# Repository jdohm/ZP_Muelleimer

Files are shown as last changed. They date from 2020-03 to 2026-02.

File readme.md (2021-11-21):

# Mülleimer Projekt der Zukunftspiloten aus dem Bergischen Land
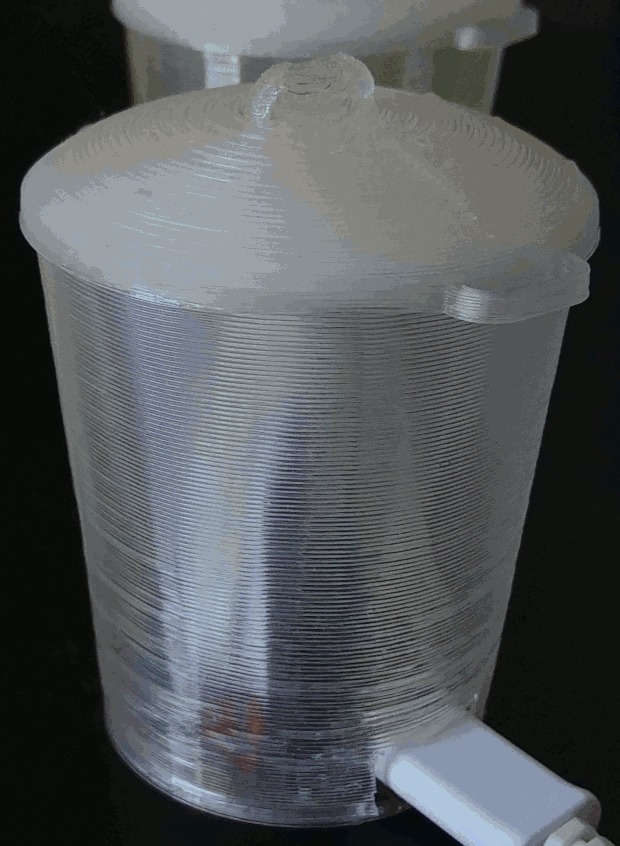
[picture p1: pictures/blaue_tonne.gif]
GIF blaue Mülltonne Abbildung vom Lötvorgang

## Zur Hardware:

| Anzahl | Bezeichnung |
|:---:|--- |
| 1 | Wemos D1 Mini ESP8266 Board  |
| 6 LED* | WS2812b LED-Streifen |
| 1 | USB-Kabel Ladekabel |
| 1 | USB-Netzteil |
| ~20g | (klares) Filament |

*wir nutzen ca 10 cm LED-Streifen (vom Typ WS2812b, mit 60 LED/Metern, also 6 LED pro Streifen. Dieser lässt sich mit 5 V unseres Boards betreiben. In der mitte geknickt passt er gut in unseren Mülleimer und zeigt so 3 LED zu jeder Seite.)

## Zum Hardware Aufbau

### Aufbau des Mülleimers
Der Mülleimer besteht aus einem 3D-Druck.
Hierzu gibt es zwei Varianten, die "simple" für Einsteiger und die "advanced" für Fortgeschrittene. 

1. Zur Erstellung des unteren 3D-Modells könnt ihr der Anleitung im Ordner 3D-Parts/bottom_simple oder 3D-Parts/bottom_advanced folgen. In beiden Ordnern befinden sich auch Beispielhaft fertige Datein. Das Ergebnis muss als *.stl exportiert werden, damit dieses später weiterverarbeitet werden kann. Speichert euch auch die Datei ab, falls ihr diese später noch einmal ändern wollt. *Hinweis* Das Modell darf innen gefüllt sein, da wir das später beim Drucken ändern.

2. Jetzt benötigen wir noch einen Deckel für unsere Tonne. Dazu findet sich ebenfalls unter 3D-Parts eine einfache Anleitung. Gerne könnt ihr natürlich auch euren eigenen Deckel kreieren. Achtet nur darauf das er auf unsere Tonne passt, und das wir den Deckel nicht im *Vasemode* Drucken. Deswegen sollten wir ihn nicht gefüllt konstruieren.

3. 3D-Drucken

    Bei dem Druck der Tonne und des Deckels brauchen wir unterschiedliche Einstellungen. Fangen wir mit der Tonne an. 
    Um eine möglichst durchscheinende Tonne zu bekommen nutzen wir nur eine Außenwand. Hier nutzen wir den *Vase mode* bei Cura heißt die Einstellung hierfür *spiralize outer contour*. Dazu nutzen wir bei einer Standard 0.4mm Düse eine *line width* von 0.48mm um unsere Tonne etwas stabiler zu gestalten. Es bietet sich an 3 *bottom layer* und eine *layer height* von 0.2-0.3mm einzustellen.

    Der einfache Deckel kann mit den Standardeinstellungen deines Druckers gedruckt werden. Eine *line width* von 0.48mm ist dabei Hilfreich aber nicht notwendig.

4. Anlöten der LED-Streifen

    Unter: [carontepass.files.wordpress.com](https://carontepass.files.wordpress.com/2016/03/wemos-d1-mini.jpg?w=1200) finden wir einen Bild mit dem Pinout des wemos D1 mini 

    Leider entpricht die Reihenfolge des LED-Streifens nicht der unseres Microkontrollers. Aus diesem Grund müssen wir mit ein paar kurzen Leitungen nachhelfen. Auch sollten wir nicht den Pin D4 nutzen, da dieser mit der internen blauen LED Verbunden ist.
    Wie hier in der Abbildung zu sehen wird die Seite des LED-Streifens auf der **Din** steht mit der Seite des Microkontrollers verbunden auf der sich die USB-Buchse befindet.

    Verbunden wird: 

    | LED | Microkontrollers |
    |:------:|-------------  |
    | +5V | 5V |
    | Din | D2 |
    | GND | G  |

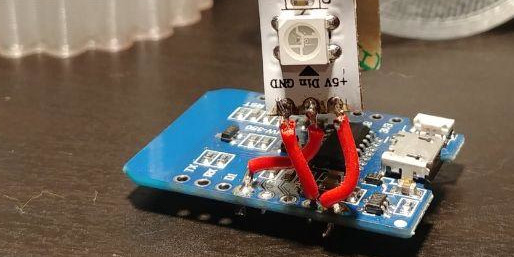
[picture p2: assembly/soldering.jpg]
Abbildung vom Lötvorgang
    

    *Hinweis* In der Arduino Umgebung heißt der Pin D2 "4". Das liegt daran das der Arduino den Wemos D1 mit den Nummern des eingebauten ESP8266 anspricht, die Hersteller vom Wemos D1 die aber umbenannt haben (zum Beispiel eben 4 in D2, oder Pin 2 in D4). Auf D4/Pin2 liegt die interne LED. Diese können wir im Arduino aber auch über *LED_BUILTIN* ansprechen.

5. Zusammenbau

    Mit einem Elektronikseitenschneider wird unten knapp über dem Boden ein Loch in unsere Tonne geschnitten sodass das kleine Ende vom USB-Kabel hindurch passt.
    Anschließend wird das Kabel hindurchgeführt, und an den Wemos D1 mini angeschlossen. Vorsichtig wird das Kabel wieder soweit hinaus gezogen, dass der Microkontroller am Boden liegt und der LED Streifen nach oben zeigt.

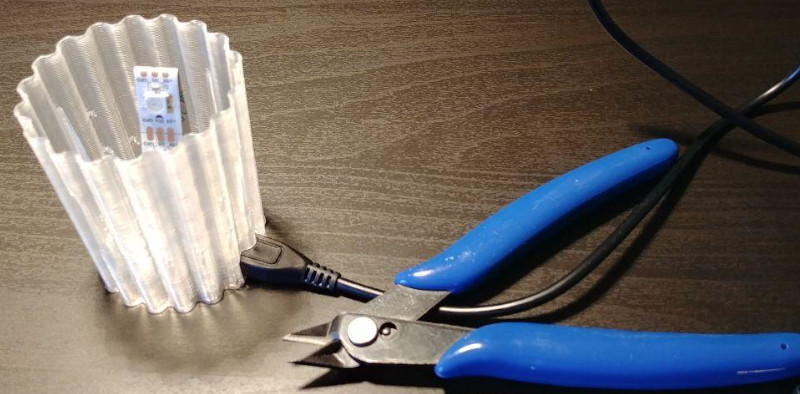
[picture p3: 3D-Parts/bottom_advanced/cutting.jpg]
Abbildung von Mülleimer und Seitenschneider
    

    Anschließend kann der Deckel einfach aufgesetzt werden.

## Zur Programmierung:

### Beschaffen und Installieren aller benötigten Bibliotheken
Ich gehe davon aus, das du bereits die Arduino IDE installiert hast, wenn nicht findest du sie hier: https://www.arduino.cc/en/software

1.   Installation des ESP8266 Moduls für Arduino https://github.com/esp8266/Arduino hier haben wir die "Installing with Boards Manager" Option gewählt. Nicht vergessend anschließend als Board den Wemos D1 R2&Mini auswählen

2.  Aus dem gleichen Set nutzen wir auch die ```ESP8266Wifi.h``` Library. Eine (englisches) Handbuch dazu findet sich hier:
[arduino-esp8266.readthedocs.io](https://arduino-esp8266.readthedocs.io/en/latest/esp8266wifi/readme.html)
hier gibt es auch ein [Beispiel Wifi Cleint](https://arduino-esp8266.readthedocs.io/en/latest/esp8266wifi/client-examples.html), bei dem ein Client aufgesetzt wird.

    Um die aktuelle Zeit und das Dazum zu kennen nutzen wir die Uhrzeit aus dem Internet. Dazu kann die folgende Anleitung genutzt werden: [simple-circuit.com](https://simple-circuit.com/esp8266-esp-01-internet-clock-wifi/). Hier wird erklärt wie wir eine Uhrzeit über NTP beziehen können. 
    Anschließend kann mit der Time Bibliothek die Linux-Uhrzeit in ein Datum umgerechnet werden. Die Informationen dazu finden wir hier: [github.com Time](https://github.com/PaulStoffregen/Time)

    * ICal (*.ics Datei) Version:

        Diese Version nutzt ICal Datein, einige Städte bieten diese zum Download für ihre Bürger an. Beispielsweise in Bochum oder Wuppertal.

        Um die Daten aus der Kalender Datei zu verwenden müssen wir den Kalender erst einmal auf unseren ESP bekommen. Dazu nutzen wir das ESP8266 Filesystem. Eine Anleitung dazu finden wir hier: [ESP Filesystem](http://arduino.esp8266.com/Arduino/versions/2.0.0/doc/filesystem.html) In dieser Anleitung wird auch erkärt, wie wir Daten von der Arduino Programmierumgebung (IDE) auf den ESP Laden.
        Hierbei muss darauf geachtet werden, die neuste Version zu nutzen, *nicht* die im Artikel verlinkte.

        Anschließend kann mit der [Github ICSParser](https://github.com/jdohm/ICSParser) Bibliothek der Kalender ausgelesen werden. 

    * Für andere Städte (Beispielsweise Remscheid) gestaltet sich das ganze etwas schwieriger. 
    
        Bei dem leichteren Fällen, kann die Information über http unverschlüsselt abgerufen werden. 
        Dazu haben wir bereits alle Infos im dem [Beispiel Wifi Cleint](https://arduino-esp8266.readthedocs.io/en/latest/esp8266wifi/client-examples.html)

        In den schwierigeren Fällen (wie auch in Remscheid) müssen wir die Information über eine verschlüsselte https Verbindung abfragen.

        Dazu stelle ich eine Passende Bibliothek zur Verfügung. Für Remscheid gibt es Beispielsweise die Bibliothek [Github RemscheidMuellParser](https://github.com/jdohm/RemscheidMuellParser) mit welcher wir (aktuell noch nicht für die gelbe Tonne) von einem Webserver abfragen ob der Müll rausgestellt werden muss.

3. Zur Steuerung der LED-Streifen fehlt uns jetzt noch eine passende Bibliothek, hier installieren wir die [github.com Neopixel](https://github.com/adafruit/Adafruit_NeoPixel) Bibliothek. Auch hier gibt es eine (englische) Anleitung. Unter "first method" gibt es eine einfache und schnelle Installationsanleitung.

Sind diese Grundlagen geschaffen geht es an die Programmierung. 

### LED Ansteuerung

Um die LED anzusteuern benötigen wir die NeoPixel Bibliothek von Adafruit.
Diese können wir mittels ```#include <Adafruit_NeoPixel.h>``` einbinden.

Im nächsten Schritt stellen wir ein wie viele LED wir haben und an welchem Pin diese angeschlossen sind. Dazu nutzen wir die Adafruit_NeoPixel funktion.

```Adafruit_NeoPixel pixels(NUMPIXELS, PIN, NEO_GRB + NEO_KHZ800);```

In dieser Funktion können wir bei NUMPIXELS einstellen wie viele LED unser LED-Streifen hat und bei PIN stellen wir ein an welchem Pin wir die LED-Datenleitung angeschlossen haben.
(Wenn du dich an die Hardware Anleitung gehalten hast, oder ein fertiges Kit erhalten hast, ist NUMPIXELS = 6 und PIN = 4.)

Im ```setup()``` können wir jetzt mittels ```pixels.begin()``` die NeoPixel Bibliothek starten.

Ist dies geschehen können wir auch schon im ```loop()``` mittels ```pixels.clear();``` alle pixel löschen oder mit ```pixels.setPixelColor(PixelNummer, pixels.Color(Rot, Grün, Blau));``` pixel setzen. Bei der Setzenfunktion müssen wir dabei für PixelNummer die Nummer des Pixels einstellen, welchen wir verändern wollen. Die Farben Rot, Grün und Blau werden mit Zahlenwerten von 0 bis 255 angegeben. Da die LED relativ hell sind, ist es am besten mit Werten unter 50 zu starten.

### Serial.print
 TODO 
### WiFi
 TODO 
### Time/NTPClient
 TODO 
### Müllabfrage
#### ICSParser - Alle Städte welche einen ICal Kalender mit den Müllterminen zur Verfügung stellen.
 Ist wie unter Installieren aller benötigten Bibliotheken beschrieben, der ICal Calender bereits auf dem WemosD1 vorhanden, können wir mit folgenden Befehlen den Müll abfragen.
 
 ```#include <ICSParser.h>``` bindet die Bibliothek zum Auslesen der Kalenderdatei ein.
 
 ```ICSParser  ICSParsery("Dateiname.ics");``` teilt dem Wemos mit, wie die Datei heißt, welche den Kalender beinhaltet.

  ```if(ICSParsery.CheckDate("Grau", day(),month(),year()))``` Fragt ab ob das Wort "Grau" am gegebenen Datum vorkommt. Die Worte können dabei an die im Kalender vorhandenen Stichworte angepasst werden.
  
#### Andere Städte
 Müssen in die Beschreibung der speziellen Bibliothek schauen (wenn Vorhanden), Fragen oder selbst aktiv werden.

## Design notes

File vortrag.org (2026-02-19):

* Übersicht

* Todo

** DONE Anzahl der Teilnehmer
   Beim ersten Termin muss die Anzahl der Teilnehmer erfasst werden, um später
   Hardware an die Teilnehmer verschicken zu können. 

** DONE Wohnort der Teilnehmer (für Programmierung)

** DONE Bestellen der benötigten Hardware

** DONE Einsammeln der Druckdatein und überprüfen auf Druckbarkeit

** DONE Drucken der Teilnehmerdaten

** WIP Versand der Teile (3D und Arduino)
   
# Vortrag start
* Maker online Kurs I
#+Title: Maker online Kurs I
#+Author: Jannis Dohm
#+Email: Dohm@posteo.net
#+OPTIONS: num:nil
# #+OPTIONS: toc:nil
#+OPTIONS: toc_depth = 2,
#+REVEAL_HLEVEL: 1
#+OPTIONS: reveal_single_file:t
# +EXPORT_FILE_NAME: Maker_online_I_Vortrag.html

** Herzlich Willkommen!

** Ziel / Inhalt des Kurses
- Erstellung der Hardware (4.11)
- Zusammenbau und Programmierung (25.11)
- Hilfe, Customization, Fragen / Reserve (16.12)
# 
# *** Zusammenbau und Programmierung (25.11)
         # Thema: Programmieren des WeMos D1 (Arduino) und die Benutzung einer ersten Bibliothek.
         # Ziel: Ein Blinkender Mülleimer, bei den fitteren gern auch schon mit einer kleinen Animation oder ähnliches.
# *** Hilfe, Customization, Fragen / Reserve (16.12)
         # Thema: Erweiterung und Automatisierung unserer Mülleimer
         # Ziel: Bei jede:r Teilnehmer:in leuchtet die Mülltonne automatische wenn der Müll raus muss.
# 
     # 2. Block - Optional - Fragen und Antworten, wenn jemand noch Probleme hat
        # oder noch selbst weiter macht.
** Heutiges Ziel
- Jeder hat FreeCAD installiert
- Jeder hat einfaches Tonnenmodell konstruiert
- Ich werde die Tonnen für euch drucken
Wer will kann seine Tonne natürlich selbst auf einem 3D-Drucker drucken!
** Bevor wir starten:
Für den weiteren ablauf, brauche ich folgende Daten:
- Anzahl TeilnehmerInnen
- Wohnorte (für Versand der Hardware und vorbereitung der Software)
** FreeCAD Einrichten
   :PROPERTIES:
   :reveal_extra_attr: data-background-iframe="https://freecad.org"
   :END:
   # :reveal_background: ./vortrag/freecad.png
   # :reveal_extra_attr: data-background-opacity="0.2"
** Erstellen der Tonne
   :PROPERTIES:
   :reveal_background: ./vortrag/freecad_can.png
   :reveal_extra_attr: data-background-opacity="0.4"
   :END:
   Live demo zum Mitmachen
** Erstellung des Basic Deckels

** Möglichkeit der Personalisierung
   Ihr habt jetzt noch etwas Zeit selbst an euren Projekten zu arbeiten! Bei fragen gerne an uns wenden.
   Spätester Abgabezeitpunkt ist Sonntag!
   Bitte denkt daran, ohne Datei könnt ihr nicht weiter mit machen, bei Problemen gerne bei uns melden (auch nach dem Kurs).

** Kontaktdaten
   #+BEGIN_SRC
   Jannis Dohm - bergisches_land@zukunftspiloten.vdi.de
   #+END_SRC
   #+BEGIN_SRC
   Thomas Kranz - thomas.kranz@vdi-mittelhessen.de
   #+END_SRC
   #+BEGIN_SRC
   weitere Infos - https://github.com/jdohm/ZP_Muelleimer
   #+END_SRC
** Danke euch
   und hoffentlich bis zum nächsten Mal :)

* Maker online Kurs II
#+Title: Maker online Kurs II
# #+Author: Jannis Dohm
#+Email: Dohm@posteo.net
#+OPTIONS: num:nil
#+OPTIONS: toc:nil
#+OPTIONS: toc_depth = 2,
#+REVEAL_HLEVEL: 1
#+OPTIONS: reveal_single_file:t
# +EXPORT_FILE_NAME: Maker_online_II_Vortrag.html

** Ziel / Inhalt des Kurses
- /Erstellung der Hardware (4.11)/
- **Zusammenbau und Programmierung (25.11)**
- Hilfe, Customization, Fragen / Reserve (16.12)
  
** Heutiges Ziel
- Alle haben Arduino installiert
- Alle können die LED's ändern und haben die Bibliotheken installiert
# 
# *** Zusammenbau und Programmierung (25.11)
         # Thema: Programmieren des WeMos D1 (Arduino) und die Benutzung einer ersten Bibliothek.
         # Ziel: Ein Blinkender Mülleimer, bei den fitteren gern auch schon mit einer kleinen Animation oder ähnliches.
# *** Hilfe, Customization, Fragen / Reserve (16.12)
         # Thema: Erweiterung und Automatisierung unserer Mülleimer
         # Ziel: Bei jede:r Teilnehmer:in leuchtet die Mülltonne automatische wenn der Müll raus muss.
# 
     # 2. Block - Optional - Fragen und Antworten, wenn jemand noch Probleme hat
        # oder noch selbst weiter macht.

** 
   :PROPERTIES:
   :reveal_background_size: 1000px
   :reveal_background: ./vortrag/programming.svg
   :END:
** 
   :PROPERTIES:
   :reveal_background_size: 1000px
   :reveal_background: ./vortrag/working.svg
   :END:
** 
   :PROPERTIES:
   :reveal_extra_attr: data-background-iframe="https://www.arduino.cc/en/software"
   :END:
# Arduino vorbereiten
*** Windows Only - Wemos D1 Treiber installieren
    Unter Windows wird ein Treiber benötigt um den WeMos D1 Mini anzusprechen. Diese findet ihr hier:
    [[https://www.wemos.cc/en/latest/ch340_driver.html]]
    Herunterladen und installieren, dann solltet ihr über die Arduino IDE mit dem Mikrocomputer sprechen können.
*** ESP8266 Modul
    Neuen Boardverwalter einfügen:

    *Datei* -> *Voreinstellungen*

    unter *Zusätzliche Boarverwalter-URLs*: den folgenden Link einfügen:

    https://arduino.esp8266.com/stable/package_esp8266com_index.json
*** LED Treiber
    Bibliothek "Neopixel" von Adafruit.
    
    *Werkzeug* -> *Bibliotheken verwalten...*
    
    Suche nach *NeoPixel strip*.
    
    Adafruit NeoPixel installieren.
*** ICSParser - Kalender lesen
    https://github.com/jdohm/ICSParser
    
    Wir brauchen die Datein "ICSParser.cpp" und "ICSParser.h"

    Beide müssen in unseren Programordner kopiert werden.
#+REVEAL: split
    Wir speichern den Skatch unter Eigene Datein *Muelleimer*.

    Die IDE legt einen Ordner mit dem gleichen Namen an.

    ICSParser.cpp und ICSParser.h unter Muelleimer speichern.
** Programmierung
   in diesem Abschnitt beginnen wir mit der Programmierung eurer Arduinos.
   Wir schauen wie weit wir kommen, wir haben noch einen Termin um mit allem fertig zu werden!
*** LED Programmieren
über *Sketch* -> *Bibliotheken einbinden* ganz nach unten scrollen und *Adafruit NeoPixel*
   fügen wir unserem Projekt die Bibliothek zur Ansteuerung des LED-Streifens hinzu.
   Die erste Zeile mit 
#+ATTR_REVEAL: :code_attribs data-line-numbers='1|3'
#+BEGIN_SRC c++
#include <rp2040_pio.h>
#+END_SRC
benötigen wir nicht, diese müssen wir löschen.
#+REVEAL: split
unser erster Code, den wir unter:
#+ATTR_REVEAL: :code_attribs data-line-numbers='1|3'
#+BEGIN_SRC c++
#include <Adafruit_NeoPixel.h>
#+END_SRC
schreiben.

#+ATTR_REVEAL: :code_attribs data-line-numbers='1|3'
#+BEGIN_SRC c++
  //wir legen fest, wie viele LEDs an unserem Streifen sind
  #define NummerLED 6 
  //wir legen fest, an welchem Pin unsere LEDs sind
  #define LEDPin  4 
  //wir nutzen die NeoPixel Bibliothek und sagen ihr wie viele LEDs wir wo haben.
  //Dazu geben wir ihr noch Infos zu den verwendeten LEDs
  Adafruit_NeoPixel LEDStreifen(NummerLED, LEDPin, NEO_GRB + NEO_KHZ800);
#+END_SRC
#+REVEAL: split
Jetzt sagen wir dem Arduino was er am start machen soll.
Dazu schreiben wir in den Bereich *setup*, zwischen die geschweiften Klammern.
Alle Befehle in diesem Bereich werden beim Setup, also dem Start einmal ausgeführt.
#+REVEAL: split
Mit:
#+ATTR_REVEAL: :code_attribs data-line-numbers='1|3'
#+BEGIN_SRC c++
  LEDStreifen.begin();
#+END_SRC

teilen wir ihm mit, das er am Anfang den LED Streifen aktivieren soll.
Mit 
#+ATTR_REVEAL: :code_attribs data-line-numbers='1|3'
#+BEGIN_SRC c++
  LEDStreifen.setPixelColor(1, LEDStreifen.Color(0,0,20));
#+END_SRC
Können wir ihm sagen, das er die erste LED blau machen soll.
#+REVEAL: split
Um das Ergebnis zu sehen müssen wir jetzt noch mit
#+ATTR_REVEAL: :code_attribs data-line-numbers='1|3'
#+BEGIN_SRC c++
  LEDStreifen.show();
#+END_SRC
mitteilen, das wir den aktuellen Stand sehen möchten.
#+REVEAL: split
Kompilieren und hochladen
#+REVEAL: split
Klappt es bei allen?
Welche LED leuchtet? Habt ihr eine Idee warum?
*** Serial Programmieren
Beim Programmieren schleichen sich schnell Fehler ein, die schwer zu finden sind.
Deswegen gibt es einen Trick, wie wir uns Nachrichten vom Arduino senden lassen können.
So wissen wir, was der Arduino als letztes getan hat oder was er nicht tut.
#+REVEAL: split
Dazu nutzen wir die Funktion *Serial*
#+BEGIN_SRC c++
  Serial.begin(115200);
#+END_SRC
Teilt dem Arduino mit, das er eine Verbindung mit unserem Computer aufbauen soll.
Die *115200* ist dabei die Geschwindigkeit der Verbindung.
Auch diesen Befehl schreiben wir in den setup Bereich, da er nur zum Start einmal ausgeführt werden soll.

#+REVEAL: split
Anschließend können wir uns mit
#+BEGIN_SRC c++
  Serial.print("Nachricht");
#+END_SRC
#+BEGIN_SRC c++
  Serial.println("Nachricht");
#+END_SRC
Nachrichten schicken, die Version mit ln am Ende schickt zusätzlich zu der Nachricht, die Information,
dass die Zeile fertig ist. Beide funktionen senden uns aber eine Nachricht.
#+REVEAL: split
Schreiben wir 
#+BEGIN_SRC c++
  //Leere Zeile um von start abzugrenzen
  Serial.println("");
  //Begrüßung
  Serial.println("Hallo Jannis");
#+END_SRC
in den setup Bereich, grüßt uns der Arduino bei jedem Start.
#+REVEAL: split
Nachrichten vom Arduino sehen wir im Seriellen Monitor

*Werkzeuge* -> *Seriellen Monitor*

Bei dem müssen wir die gleiche Geschwindigkeit einstellen wie im Program.

# *** WiFi (W-Lan)
#Unser W-Lan Passwort ist geheim, deswegen zeige ich euch einen Trick, wie wir es verstecken können.
#Dazu nutzen wir eine gehemeine Datei *secrets.h*.
##+REVEAL: split
#Wir erstellen eine neue Datei. Das geht gut mit dem Editor (oder einem anderen Texteditor, wie z.B. gedit).
#Diese Datei werden wir später in unser Projekt einbinden, deswegen tun wir sie in den gleichen Ordner.
#
#Wir schreiben in diese Datei den folgenden Inhalt:
#
##+BEGIN_SRC c++
##define WlanName	"Name_eures_Wlans"
##define WlanPasswort	"euer_Passwort"
##+END_SRC
#und speichern die Datei unter "secrets.h"
##+REVEAL: split
#
#Die Datei können wir jetzt im Hauptprogram einbinden.
#Dazu schreiben wir oben unter
#
##+BEGIN_SRC c++
##include <Adafruit_NeoPixel.h>
##+END_SRC
#
#noch
#
##+BEGIN_SRC c++
##include "secrets.h"
##+END_SRC
#
##+REVEAL: split
#
#mit
##+BEGIN_SRC c++
 #Serial.println(WlanName);
##+END_SRC
#können wir uns jetzt ausgeben lassen, wie unser W-Lan heißt. Wenn das Klappt kennt der Arduino jetzt also den Namen unseres W-Lans.
#
##+REVEAL: split
#
#Verbindung zum WLAN
#
#Bibliothek einfügen *Sketch* -> *Bibliothek einfügen* -> *ESP8266WiFi*
#
##+REVEAL: split
##+BEGIN_SRC c++
  #WiFi.begin(WlanName,WlanPasswort);
  #Serial.print("Verbinden mit Wlan ");
  #while (WiFi.status() != WL_CONNECTED)
  #{
    #Serial.print(".");
    #delay(500);
  #}
##+END_SRC
    #
  #Serial.print("\nVerbunden, IP Addresse: ");
  #Serial.println(WiFi.localIP());
#
  #
#Der nächste Schritt ist die Verbindung zum W-Lan.
#Dazu nutzen wir die folgende Funktion:
#
#verbinden... (mit Serial)                                                             
# *** NTP (Zeiten aus dem Netz)
#Zeit empfangen
#
#Umrechnen
#
#Ausgeben     
# *** LittleFS
# *** ICSParser
# *** Custom
# *** Zusammenführen
*** Danke

* Maker online Kurs III
#+Title: Maker online Kurs III
# #+Author: Jannis Dohm
#+Email: Dohm@posteo.net
#+OPTIONS: num:nil
#+OPTIONS: toc:nil
#+OPTIONS: toc_depth = 2,
#+REVEAL_HLEVEL: 1
#+OPTIONS: reveal_single_file:t
#+EXPORT_FILE_NAME: Maker_online_III_Vortrag.html

** Ziel / Inhalt des Kurses
- /Erstellung der Hardware (4.11)/
- /Zusammenbau und Programmierung (25.11)/
- **Hilfe, Customization, Fragen / Reserve (16.12)**
  
** Heutiges Ziel
- Alle können sich mit WLAN verbinden
- Alle haben die aktuelle Zeit auf Wemos D1 mini
- Alle haben den Kalender auf dem Wemos
- Bei allen leuchtet eine LED wenn der Müll raus muss
  
** Programmierung
   in diesem Abschnitt beginnen wir mit der Programmierung eurer Arduinos.
   Wir schauen wie weit wir kommen, wir haben noch einen Termin um mit allem fertig zu werden!
*** WiFi (WLAN)
Unser WLAN Passwort ist geheim, deswegen zeige ich euch einen Trick, wie wir es verstecken können.
Dazu nutzen wir eine gehemeine Datei *secrets.h*.
#+REVEAL: split
Wir erstellen eine neue Datei. Das geht in der Arduino IDE in dem wir oben rechts auf den Pfeil nach unten klicken und *neue Datei* wählen.

Als Name wählen wir *secrets.h* 
Die Datei wird automatisch im gleichen Ordner gespeichert, sodass wir sie im Programm nutzen können. 

Wir schreiben in diese Datei den folgenden Inhalt:

#+BEGIN_SRC c++
#define WlanName	"Name_eures_Wlans"
#define WlanPasswort	"euer_Passwort"
#+END_SRC
und speichern.
#+REVEAL: split

Die Datei können wir jetzt im Hauptprogram einbinden.
Dazu schreiben wir oben unter

#+BEGIN_SRC c++
#include <Adafruit_NeoPixel.h>
#+END_SRC

noch

#+BEGIN_SRC c++
#include "secrets.h"
#+END_SRC

#+REVEAL: split

mit
#+BEGIN_SRC c++
 Serial.print("mein WLAN heißt: ");
 Serial.println(WlanName);
#+END_SRC
können wir uns jetzt ausgeben lassen, wie unser W-Lan heißt. Wenn das Klappt kennt der Arduino jetzt also den Namen unseres W-Lans.

#+REVEAL: split

Verbindung zum WLAN

Bibliothek einfügen *Sketch* -> *Bibliothek einfügen* -> *ESP8266WiFi*

#+REVEAL: split
Der nächste Schritt ist die Verbindung zum W-Lan.
Dazu nutzen wir die folgende Funktion:
#+BEGIN_SRC c++
  WiFi.begin(WlanName,WlanPasswort);
  Serial.print("Verbinden mit Wlan ");
  while (WiFi.status() != WL_CONNECTED)
  {
    Serial.print(".");
    delay(500);
  }
    
  Serial.println();
  Serial.print("Verbunden, IP Addresse: ");
  Serial.println(WiFi.localIP());
#+END_SRC

*** NTP Network Time Protocoll (Zeiten aus dem Netz)
*WiFiUdp.h* und *WiFiUdp.cpp* von hier:

[[https://github.com/arduino-libraries/NTPClient]]

herunter laden und in den Ordner Muelleimer speichern.

#+REVEAL: split

unnter die anderen includes folgendes einfügen: 

#+BEGIN_SRC c++
#include "NTPClient.h"
#+END_SRC

Mit folgendem Code konfigurieren wir, wie wir die Zeit erhalten möchten.
#+BEGIN_SRC c++
  // UDP zugang über WLAN
  WiFiUDP ntpUDP;
  // Funktion  unsereInstanz
  //    |          |     Art   , Zeitserver    , Zeitverschiebung zu UTC in Sekunden
  //    |          |       |              |        | , Abfrage alle 60000 Millisekunden
  NTPClient timeClient(ntpUDP, "pool.ntp.org", 3600, 60000);
#+END_SRC

#+REVEAL: split
Mit folgendem Code im Bereich setup, starten wir unseren timeClient
#+BEGIN_SRC c++
timeClient.begin();
#+END_SRC

und mit folgendem Code teilen wir mit, das die Zeit abgefragt werden soll:
#+BEGIN_SRC c++
timeClient.update();
#+END_SRC

Anschließend können wir mit dem folgenden Code die Uhrzeit ausgeben:
#+BEGIN_SRC c++
Serial.println(timeClient.getFormattedTime());
#+END_SRC

#+REVEAL: split
Für das Datum gibt es leider keine ganz so einfache Funktion.
Wir können aber die aktuelle [[https://de.wikipedia.org/wiki/Unixzeit][Unixzeit]] mit
#+BEGIN_SRC c++
timeClient.getEpochTime();
#+END_SRC
erhalten.
#+REVEAL: split
Diese können wir mit einer Zeit Bibliothek dem Arduino mitteilen.

Dazu müssen wir unter *Sketch* -> *Bibliotheken einbinden* -> *Bibliotheken verwalten...*
nach "Timekeeping functionality" suchen und *Time* by Paul Stoffregen installieren.

Anschließend können wir unter *Sketch* -> *Bibliotheken einbinden* die Time Bibliothek hinzufügen.

#+REVEAL: split
Mit:
#+BEGIN_SRC c++
  //nach dem timeClient.update()
  setTime(timeClient.getEpochTime());
#+END_SRC
können wir die aktuelle Uhrzeit auf dem WeMos setzen.

# Timekeeping functionality for Arduino Date and Time functions, with provisions to syncronize to external time sources like GPS and NTP (Internet). This library is often used together with TimeAlarms and DS1307TRC.
#+REVEAL: split
Mit folgendem Code können wir uns das aktuelle Datum und die aktuelle Uhrzeit ausgeben lassen:

#+BEGIN_SRC c++
  Serial.print("Datum: ");
  Serial.print(day());
  Serial.print(".");
  Serial.print(month());
  Serial.print(".");
  Serial.println(year());
  Serial.print("Time: ");
  Serial.println(timeClient.getFormattedTime());
#+END_SRC

*** ICSParser
Mit dem ICSParser können iCal Kalender ausgelesen werden.

Wir nutzen ihn, um in einer .ICS Datei zu sehen, wann die Müllabfuhr kommt.

Dazu müssen wir die Zip-Datei unter [[https://github.com/jdohm/ICSParser/releases/download/v0.1.0-beta/ICSParserv0.1.0.zip][ICSParserv0.1.0]] herunterladen.

Die zwei Dateien speichern wir in unserem *Muelleimer* Ordner.
#+REVEAL: split
Mit dem folgenden Code, am Anfang unseres Programms, können wir die Bibliothek einbinden.
#+BEGIN_SRC c++
#include "ICSParser.h"
#+END_SRC
#+REVEAL: split

Als nächstes brauchen wir den Kalender.

Diesen müssen wir von unserer Kommune herunterladen
und die iCal Datei im *Muelleimer* Ordner in einem neuen Ordner namens *data* speichern.
Der Einfachheit halber benennen wir die Datei um in *Kalender.ics*.

Um diese Datei auf den Arduino zu bekommen installieren wir LittleFS.
#+REVEAL: split
Unser Ordner Meulleimer müsste jetzt die folgenden Dateien enthalten:
#+BEGIN_SRC c++
  Muelleimer\
  - Muelleimer.ino
  - secrets.h
  - NTPClient.h
  - NTPClient.cpp
  - ICSParser.h
  - ICSParser.cpp
  - data\
    - Kalender.ics
#+END_SRC
    
*** LittleFS
Mit LittleFS (kleines Dateisystem) können wir einen Kalender auf dem Arduino speichern.

Zuerst müssen wir dazu den das folgende Zip [[https://github.com/earlephilhower/arduino-esp8266littlefs-plugin/releases/download/2.6.0/ESP8266LittleFS-2.6.0.zip][LittleFS Tool]] unter
#+BEGIN_SRC c++
<home_dir>/Arduino/tools/
#+END_SRC
entpacken anschließend muss die Arduino IDE neugestartet werden.
#+REVEAL: split
Mit *Werkzeuge* -> *ESP8266 Sketch Data Upload*

können anschließend die Daten die wir unter *data* gespeichert haben

auf den Arduino hochgeladen werden.

*** Zusammenführen
Jetzt können wir alles zusammen bringen. Mit dem folgenden Code im Setup
#+BEGIN_SRC c++
ICSParser KalenderLeser("Kalender.ics");
#+END_SRC
sagen wir dem ICSParser das wir ihn KalenderLeser nennen und er die Datei Kalender.ics lesen soll.
#+REVEAL: split
#+BEGIN_SRC c++
  //         Was suchen wir?
  //           |    an welchem Tag?
  //           |     |  in welchem Monat?
  //           |     |  |  in welchem Jahr?
  CheckDate("Grau", 13, 3, 2020);
#+END_SRC
fragt anschließend ab, ob an einem gegebenen Tag, ein bestimmtes Event im Kalender eingetragen ist.
#+REVEAL: split
Um zu testen, ob es bereits funktioniert, 
können wir mit die Kalender.ics Datei in einem Texteditor öffnen
und uns einen Tag raus suchen an dem es einen Eintrag gibt.

Anschließend können wir testen, ob der Kalender den Eintrag auch findet.

#+REVEAL: split
Dazu nutzen wir folgenden Code:
#+BEGIN_SRC c++
  Serial.print("Muss der Müll raus? ");
  Serial.println(KalenderLeser.CheckDate("Grau", 16, 12, 2021));
#+END_SRC
Jetzt sagt der Arduino uns im Serialmonitor mit *1* oder *0* ob er denkt der Müll muss an diesem Tag raus.
#+REVEAL: split
Mit einer guten Kombination können wir jetzt automatisch jeden Tag abfragen,
 ob der Müll am nächsten Tag raus muss.
 Um nicht immer auf den Serialmonitor angewisen zu sein, können wir auch die LEDs nutzen.

Dazu noch ein Tipp:
#+BEGIN_SRC c++
  //Einen Tag in Sekunden hinzufügen
  setTime(timeClient.getEpochTime()+86400);
#+END_SRC
# muss hier sein, da sonst bei day()+1 aus 31 -> 32 wird, anstelle des nächsten Monats
*** Viel Erfolg!
    lasst es uns gemeinsam versuchen
*** Danke

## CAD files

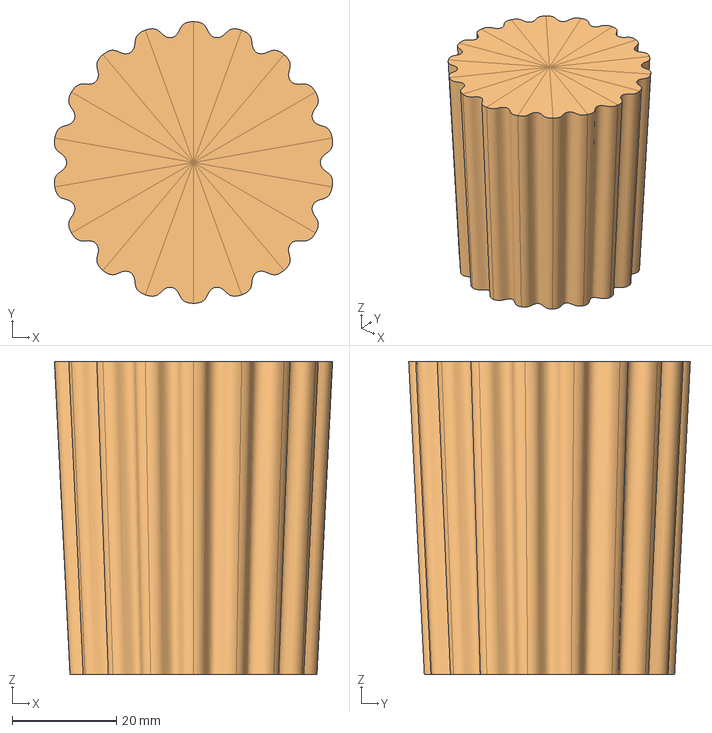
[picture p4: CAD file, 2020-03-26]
3D-Parts/bottom_advanced/Trashcan_bottom.FCStd
53.3 x 54.0 x 60.0 mm

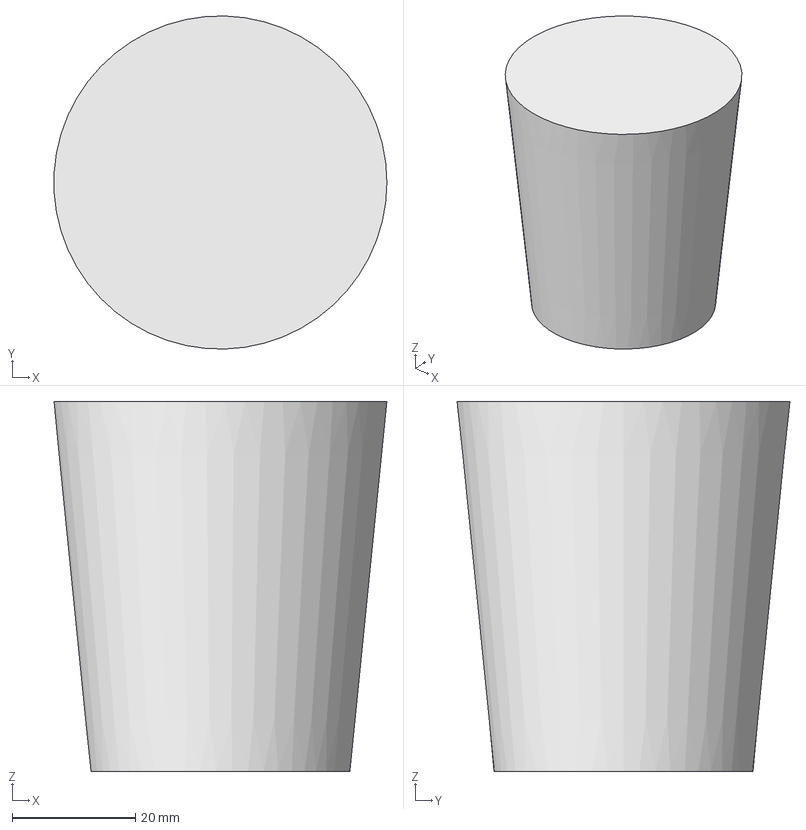
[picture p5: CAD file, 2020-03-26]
3D-Parts/bottom_simple/Trashcan_bottom.FCStd
54.0 x 54.0 x 60.0 mm

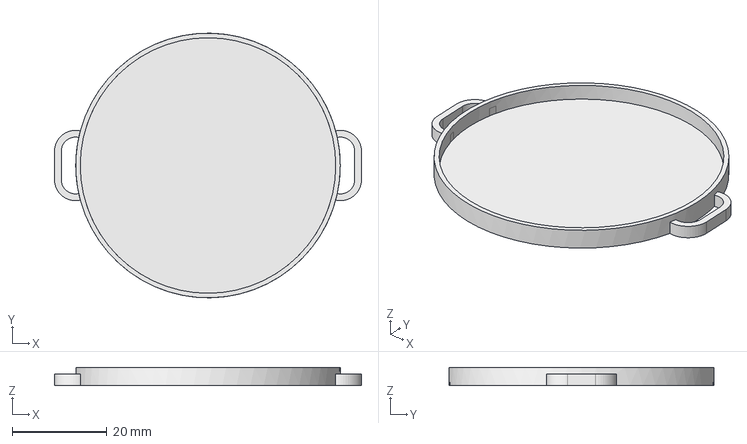
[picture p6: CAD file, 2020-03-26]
3D-Parts/top_simple/top_simple.FCStd
64.9 x 55.9 x 3.90 mm

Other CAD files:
3D-Parts/top_advanced/top_advanced.FCStd
3D-Parts/bottom_advanced/Trashcan_bottom.stl
3D-Parts/bottom_simple/Trashcan_bottom.stl
3D-Parts/top_simple/top_simple.stl

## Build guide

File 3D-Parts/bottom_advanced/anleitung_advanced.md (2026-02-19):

# Anleitung gewellter Mülleimer

Hier ekläre ich wie mittels des freien Programms FreeCAD https://freecad.org ein etwas komplizierterer Mülleimer creirt werden kann.

## Vorläufig: (aktueller Stand in Video (noch nicht veröffentlicht))
Diese Datei ist aktuell nur enthalten um zu einem Späteren Zeitpunkt angepasst zu werden

**Die Datein Trashcan_bottom sind allerdings einsatzbereit!**

1. Wir öffnen ein neues Projekt in FreeCAD im der Part Design Workbench. Dort wählen wir "Körper erstellen"

2. Erstellen eines Sketches in der xy Ebene

3. Hier erstellen wir zwei kreise um den Mittelpunkt. 
Der kleinere erhält einen Radius von 20,65 mm (Dadurch passt später der wemos D1 ins innere).

4. Als nächstes legen wir einen B-Spline an. Dieser erhält 4 Punkte. Der Startpunkt liegt dabei auf dem äußeren Kreis, die zwei nächsten zwischen den Kreisen und der letzte liegt auf dem inneren Kreis.

5. Jetzt legen wir zwischen den Punkten auf dem Kreis und den Kreisen eine tangential Bedingung an (Tangente zwischen zwei Elementen erzwingen (T)).

6. Der innere Punkt wird jetzt auf die X-Achse gelegt (Punkt auf ein Objekt festlegen (Umschalt+O))

7. Der äußere Punkt soll auf 10° des Kreises eingestellt werden. Da wir nur Linien mit einer Winkelbedingung belegen können, legen wir eine Hilfslienie vom Nullpunkt bis zum äußeren Kreis an. Diese bemaßen wir mit 10°.
Als nächstes legen wir den äußeren Punkt unserer B-Spline auf diese Hilfslinie (mittels Punkt auf ein Objekt festlegen (Umschalt+O)).

8. Die zwei Kreise und die Hilfslinie dienten uns nur zur Konstruktion, diese können jetzt als Hilfslienie gesetz werden. 

9. Wir spiegeln unsere gesetzte B-Spline um die X-Achse

10. Wir schließen den Sketch und wechseln in die Draft Workbench.

11. Hier wählen wir den Sketch in der Combo-Ansicht aus. Dann wählen wir das Array Tool.

12. Der "Array Type" wird auf "polar" geändert. Dazu wird die "Number Polar" auf 18 geändert. Wenn anschließend aktualisiert wird erhalten wir bereits die Bodenplatte unseres Mülleimers!

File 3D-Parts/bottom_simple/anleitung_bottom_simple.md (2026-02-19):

# Anleitung einfacher Mülleimer

Hier ekläre ich wie mittels des freien Programms FreeCAD https://freecad.org einen einfachen Mülleimer creirt werden kann.

1. Wir öffnen ein neues Projekt in FreeCAD, und wechseln in die Part Design Workbench.
    Part Design 
    Dort wählen wir "Körper erstellen" Körper erstellen

2. Erstellen eines Skizze in der xz Ebene

3. Hier erstellen wir eine Linienzug Linienzug mit der starten wir am Nullpunkt. Gehen auf der X-Achse nach rechts, dann hoch (nicht vertikal), nach links auf die Z-Achse (horizontal) und den letzten Punkt erneut in den Nullpunkt.

4. Der nächste Schritt ist die bemaßung. Dazu nutzen wir den horizontalen und vertikalen Abstand Abstände. Den unteren Abstand stellen wir auf 21mm ein, den oberen auf 27mm, als letztes geben wir die höhe mit 60mm an.
Das Ganze sollte jetzt in etwas so aussehen:
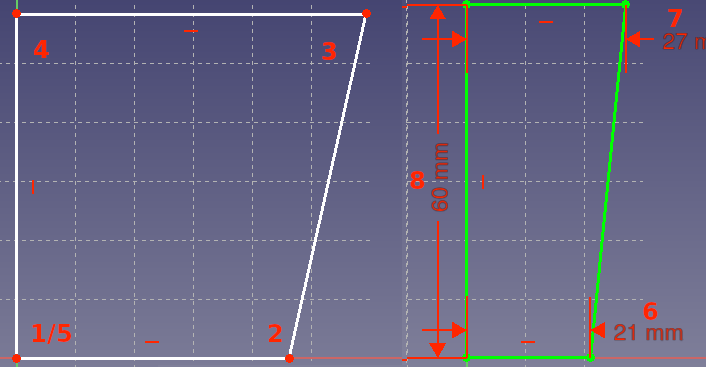
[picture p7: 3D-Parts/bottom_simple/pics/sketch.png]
Skizze


5. Jetzt verlassen wir die Skizze schließen

6. Der letzte Schritt für dieses Teil ist eine Rotation rotation, hier stimmen die Parameter bereits. Wir rotieren um die "Vertikale Skizzenachse" um 360° und klicken auf OK.

7. Jetzt fehlt nur noch ein Sichern der Datei und ein exportieren (Datei->Exportieren) als *.stl um die Datei später weiter verarbeiten zu können. *Hinweis* bei dem exportieren muss darauf geachtet werden das im Strukturbaum das Bauteil ausgewählt wurde (das Bauteil wird grün in der rechten Ansicht), sonst wird nur eine leere Datei exportiert.

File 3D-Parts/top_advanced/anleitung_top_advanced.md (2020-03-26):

# Anleitung für den advanced Deckel

1. Wir öffnen ein neues Projekt in FreeCAD, und wechseln in die Part Design Workbench.
    Part Design 
    Dort wählen wir "Körper erstellen" Körper erstellen

2. Erstellen eines Skizze in der xz Ebene

3. Hier beginnen wir mit einem B-Spline B-Spline, mit dieser starten wir auf der Z-Achse. Im gleichen Schritt machen wir 2 weitere Punkte rechts davon. Wir beenden mit der Esc Taste.

4. Als nächstes erzeugen wir wieder einen Linienzug Linienzug mit dem starten wir am Ende unserer B-Spline und gehen gerade runter auf die X-Achse.

4. Der nächste Schritt ist die bemaßung. Dazu nutzen wir den horizontalen und vertikalen Abstand Abstände. 
Hier stellen wir einen Abstand von dem Nullpunkt zu unserer geraden auf der X-Achse von 27mm ein. Die höhe der Linie legen wir auf 3mm fest. Jetzt schieben wir die Punkte der B-Spline so, dass wir eine schöne Form für einen Mülleimerdeckel erhalten.... 

## Advanced Anleitung muss noch erstellt werden!
Gestaltet sich zumindest in FreeCAD schwieriger als erwartet. Ich möchte aber ungern eine Anleitung für Fusion 360 erstellen, da Fusion 360 nicht jedem zur Verfügung steht.

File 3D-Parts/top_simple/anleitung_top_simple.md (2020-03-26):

# Anleitung für den einfachen Deckel

1. Wir öffnen ein neues Projekt in FreeCAD, und wechseln in die Part Design Workbench.
    Part Design 
    Dort wählen wir "Körper erstellen" Körper erstellen

2. Erstellen eines Skizze in der xz Ebene

3. Hier erstellen wir eine Linienzug Linienzug mit der starten wir am Nullpunkt. Folgende Form sollte erzeugt werden:
Skizze

4. Der nächste Schritt ist die bemaßung. Dazu nutzen wir den horizontalen und vertikalen Abstand Abstände. Hier stellen wir die folgenden Maße ein:
Skizze
Danach verlassen wir die Skizze über schließen.

5. Jetzt nutzen wir die Rotation rotation, hier stimmen die Parameter bereits. Wir rotieren um die "Vertikale Skizzenachse" um 360° und klicken auf OK.

6. Wer möchte kann jetzt noch Griffe an seinen Deckel konstruieren. 
Hierzu gibt es keine Anleitung, da wir die nicht zwingend brauchen und es eine gute Übung ist. Bei Fragen meldet euch gerne bei mir.

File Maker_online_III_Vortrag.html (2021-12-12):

# Maker online Kurs III

## Jannis Dohm

Created: 2021-12-11 Sa 16:05

## Ziel / Inhalt des Kurses

- Erstellung der Hardware (4.11)
- Zusammenbau und Programmierung (25.11)
- Hilfe, Customization, Fragen / Reserve (16.12)

## Heutiges Ziel

- Alle können sich mit WLAN verbinden
- Alle haben die aktuelle Zeit auf Wemos D1 mini
- Alle haben den Kalender auf dem Wemos
- Bei allen leuchtet eine LED wenn der Müll raus muss

## Programmierung

in diesem Abschnitt beginnen wir mit der Programmierung eurer Arduinos. Wir schauen wie weit wir kommen, wir haben noch einen Termin um mit allem fertig zu werden!

### WiFi (WLAN)

Unser WLAN Passwort ist geheim, deswegen zeige ich euch einen Trick, wie wir es verstecken können. Dazu nutzen wir eine gehemeine Datei secrets.h.

Wir erstellen eine neue Datei. Das geht in der Arduino IDE in dem wir oben rechts auf den Pfeil nach unten klicken und neue Datei wählen.

Als Name wählen wir secrets.h Die Datei wird automatisch im gleichen Ordner gespeichert, sodass wir sie im Programm nutzen können.

Wir schreiben in diese Datei den folgenden Inhalt:

#define WlanName  "Name_eures_Wlans"
#define WlanPasswort  "euer_Passwort"

und speichern.

Die Datei können wir jetzt im Hauptprogram einbinden. Dazu schreiben wir oben unter

#include <Adafruit_NeoPixel.h>

noch

#include "secrets.h"

mit

Serial.print("mein WLAN heißt: ");
Serial.println(WlanName);

können wir uns jetzt ausgeben lassen, wie unser W-Lan heißt. Wenn das Klappt kennt der Arduino jetzt also den Namen unseres W-Lans.

Verbindung zum WLAN

Bibliothek einfügen Sketch -> Bibliothek einfügen -> ESP8266WiFi

Der nächste Schritt ist die Verbindung zum W-Lan. Dazu nutzen wir die folgende Funktion:

WiFi.begin(WlanName,WlanPasswort);
Serial.print("Verbinden mit Wlan ");
while (WiFi.status() != WL_CONNECTED)
{
  Serial.print(".");
  delay(500);
}

Serial.println();
Serial.print("Verbunden, IP Addresse: ");
Serial.println(WiFi.localIP());

### NTP Network Time Protocoll (Zeiten aus dem Netz)

WiFiUdp.h und WiFiUdp.cpp von hier:

https://github.com/arduino-libraries/NTPClient

herunter laden und in den Ordner Muelleimer speichern.

unnter die anderen includes folgendes einfügen:

#include "NTPClient.h"

Mit folgendem Code konfigurieren wir, wie wir die Zeit erhalten möchten.

// UDP zugang über WLAN
WiFiUDP ntpUDP;
// Funktion  unsereInstanz
//    |          |     Art   , Zeitserver    , Zeitverschiebung zu UTC in Sekunden
//    |          |       |              |        | , Abfrage alle 60000 Millisekunden
NTPClient timeClient(ntpUDP, "pool.ntp.org", 3600, 60000);

Mit folgendem Code im Bereich setup, starten wir unseren timeClient

timeClient.begin();

und mit folgendem Code teilen wir mit, das die Zeit abgefragt werden soll:

timeClient.update();

Anschließend können wir mit dem folgenden Code die Uhrzeit ausgeben:

Serial.println(timeClient.getFormattedTime());

Für das Datum gibt es leider keine ganz so einfache Funktion. Wir können aber die aktuelle Unixzeit (https://de.wikipedia.org/wiki/Unixzeit) mit

timeClient.getEpochTime();

erhalten.

Diese können wir mit einer Zeit Bibliothek dem Arduino mitteilen.

Dazu müssen wir unter Sketch -> Bibliotheken einbinden -> Bibliotheken verwalten… nach "Timekeeping functionality" suchen und Time by Paul Stoffregen installieren.

Anschließend können wir unter Sketch -> Bibliotheken einbinden die Time Bibliothek hinzufügen.

Mit:

//nach dem timeClient.update()
setTime(timeClient.getEpochTime());

können wir die aktuelle Uhrzeit auf dem WeMos setzen.

Mit folgendem Code können wir uns das aktuelle Datum und die aktuelle Uhrzeit ausgeben lassen:

Serial.print("Datum: ");
Serial.print(day());
Serial.print(".");
Serial.print(month());
Serial.print(".");
Serial.println(year());
Serial.print("Time: ");
Serial.println(timeClient.getFormattedTime());

### ICSParser

Mit dem ICSParser können iCal Kalender ausgelesen werden.

Wir nutzen ihn, um in einer .ICS Datei zu sehen, wann die Müllabfuhr kommt.

Dazu müssen wir die Zip-Datei unter ICSParserv0.1.0 (https://github.com/jdohm/ICSParser/releases/download/v0.1.0-beta/ICSParserv0.1.0.zip) herunterladen.

Die zwei Dateien speichern wir in unserem Muelleimer Ordner.

Mit dem folgenden Code, am Anfang unseres Programms, können wir die Bibliothek einbinden.

#include "ICSParser.h"

Als nächstes brauchen wir den Kalender.

Diesen müssen wir von unserer Kommune herunterladen und die iCal Datei im Muelleimer Ordner in einem neuen Ordner namens data speichern. Der Einfachheit halber benennen wir die Datei um in Kalender.ics.

Um diese Datei auf den Arduino zu bekommen installieren wir LittleFS.

Unser Ordner Meulleimer müsste jetzt die folgenden Dateien enthalten:

Muelleimer\
- Muelleimer.ino
- secrets.h
- NTPClient.h
- NTPClient.cpp
- ICSParser.h
- ICSParser.cpp
- data\
  - Kalender.ics

### LittleFS

Mit LittleFS (kleines Dateisystem) können wir einen Kalender auf dem Arduino speichern.

Zuerst müssen wir dazu den das folgende Zip LittleFS Tool (https://github.com/earlephilhower/arduino-esp8266littlefs-plugin/releases/download/2.6.0/ESP8266LittleFS-2.6.0.zip) unter

<home_dir>/Arduino/tools/

entpacken anschließend muss die Arduino IDE neugestartet werden.

Mit Werkzeuge -> ESP8266 Sketch Data Upload

können anschließend die Daten die wir unter data gespeichert haben

auf den Arduino hochgeladen werden.

### Zusammenführen

Jetzt können wir alles zusammen bringen. Mit dem folgenden Code im Setup

ICSParser KalenderLeser("Kalender.ics");

sagen wir dem ICSParser das wir ihn KalenderLeser nennen und er die Datei Kalender.ics lesen soll.

//         Was suchen wir?
//           |    an welchem Tag?
//           |     |  in welchem Monat?
//           |     |  |  in welchem Jahr?
CheckDate("Grau", 13, 3, 2020);

fragt anschließend ab, ob an einem gegebenen Tag, ein bestimmtes Event im Kalender eingetragen ist.

Um zu testen, ob es bereits funktioniert, können wir mit die Kalender.ics Datei in einem Texteditor öffnen und uns einen Tag raus suchen an dem es einen Eintrag gibt.

Anschließend können wir testen, ob der Kalender den Eintrag auch findet.

Dazu nutzen wir folgenden Code:

Serial.print("Muss der Müll raus? ");
Serial.println(KalenderLeser.CheckDate("Grau", 16, 12, 2021));

Jetzt sagt der Arduino uns im Serialmonitor mit 1 oder 0 ob er denkt der Müll muss an diesem Tag raus.

Mit einer guten Kombination können wir jetzt automatisch jeden Tag abfragen, ob der Müll am nächsten Tag raus muss. Um nicht immer auf den Serialmonitor angewisen zu sein, können wir auch die LEDs nutzen.

Dazu noch ein Tipp:

//Einen Tag in Sekunden hinzufügen
setTime(timeClient.getEpochTime()+86400);

### Viel Erfolg!

lasst es uns gemeinsam versuchen

### Danke

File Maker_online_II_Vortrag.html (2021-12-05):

# Maker online Kurs II

## Jannis Dohm

Created: 2021-12-05 So 23:22

## Ziel / Inhalt des Kurses

- Erstellung der Hardware (4.11)
- Zusammenbau und Programmierung (25.11)
- Hilfe, Customization, Fragen / Reserve (16.12)

## Heutiges Ziel

- Alle haben Arduino installiert
- Alle können die LED's ändern und haben die Bibliotheken installiert

### Windows Only - Wemos D1 Treiber installieren

Unter Windows wird ein Treiber benötigt um den WeMos D1 Mini anzusprechen. Diese findet ihr hier: https://www.wemos.cc/en/latest/ch340_driver.html Herunterladen und installieren, dann solltet ihr über die Arduino IDE mit dem Mikrocomputer sprechen können.

### ESP8266 Modul

Neuen Boardverwalter einfügen:

Datei -> Voreinstellungen

unter Zusätzliche Boarverwalter-URLs: den folgenden Link einfügen:

https://arduino.esp8266.com/stable/package_esp8266com_index.json

### LED Treiber

Bibliothek "Neopixel" von Adafruit.

Werkzeug -> Bibliotheken verwalten…

Suche nach NeoPixel strip.

Adafruit NeoPixel installieren.

### ICSParser - Kalender lesen

https://github.com/jdohm/ICSParser

Wir brauchen die Datein "ICSParser.cpp" und "ICSParser.h"

Beide müssen in unseren Programordner kopiert werden.

Wir speichern den Skatch unter Eigene Datein Muelleimer.

Die IDE legt einen Ordner mit dem gleichen Namen an.

ICSParser.cpp und ICSParser.h unter Muelleimer speichern.

## Programmierung

in diesem Abschnitt beginnen wir mit der Programmierung eurer Arduinos. Wir schauen wie weit wir kommen, wir haben noch einen Termin um mit allem fertig zu werden!

### LED Programmieren

über Sketch -> Bibliotheken einbinden ganz nach unten scrollen und Adafruit NeoPixel fügen wir unserem Projekt die Bibliothek zur Ansteuerung des LED-Streifens hinzu. Die erste Zeile mit

#include <rp2040_pio.h>

benötigen wir nicht, diese müssen wir löschen.

unser erster Code, den wir unter:

#include <Adafruit_NeoPixel.h>

schreiben.

//wir legen fest, wie viele LEDs an unserem Streifen sind
#define NummerLED 6 
//wir legen fest, an welchem Pin unsere LEDs sind
#define LEDPin  4 
//wir nutzen die NeoPixel Bibliothek und sagen ihr wie viele LEDs wir wo haben.
//Dazu geben wir ihr noch Infos zu den verwendeten LEDs
Adafruit_NeoPixel LEDStreifen(NummerLED, LEDPin, NEO_GRB + NEO_KHZ800);

Jetzt sagen wir dem Arduino was er am start machen soll. Dazu schreiben wir in den Bereich setup, zwischen die geschweiften Klammern. Alle Befehle in diesem Bereich werden beim Setup, also dem Start einmal ausgeführt.

Mit:

LEDStreifen.begin();

teilen wir ihm mit, das er am Anfang den LED Streifen aktivieren soll. Mit

LEDStreifen.setPixelColor(1, LEDStreifen.Color(0,0,20));

Können wir ihm sagen, das er die erste LED blau machen soll.

Um das Ergebnis zu sehen müssen wir jetzt noch mit

LEDStreifen.show();

mitteilen, das wir den aktuellen Stand sehen möchten.

Kompilieren und hochladen

Klappt es bei allen? Welche LED leuchtet? Habt ihr eine Idee warum?

### Serial Programmieren

Beim Programmieren schleichen sich schnell Fehler ein, die schwer zu finden sind. Deswegen gibt es einen Trick, wie wir uns Nachrichten vom Arduino senden lassen können. So wissen wir, was der Arduino als letztes getan hat oder was er nicht tut.

Dazu nutzen wir die Funktion Serial

Serial.begin(115200);

Teilt dem Arduino mit, das er eine Verbindung mit unserem Computer aufbauen soll. Die 115200 ist dabei die Geschwindigkeit der Verbindung. Auch diesen Befehl schreiben wir in den setup Bereich, da er nur zum Start einmal ausgeführt werden soll.

Anschließend können wir uns mit

Serial.print("Nachricht");

Serial.println("Nachricht");

Nachrichten schicken, die Version mit ln am Ende schickt zusätzlich zu der Nachricht, die Information, dass die Zeile fertig ist. Beide funktionen senden uns aber eine Nachricht.

Schreiben wir

//Leere Zeile um von start abzugrenzen
Serial.println("");
//Begrüßung
Serial.println("Hallo Jannis");

in den setup Bereich, grüßt uns der Arduino bei jedem Start.

Nachrichten vom Arduino sehen wir im Seriellen Monitor

Werkzeuge -> Seriellen Monitor

Bei dem müssen wir die gleiche Geschwindigkeit einstellen wie im Program.

#Unser W-Lan Passwort ist geheim, deswegen zeige ich euch einen Trick, wie wir es verstecken können. #Dazu nutzen wir eine gehemeine Datei secret.h. ##+REVEAL: split #Wir erstellen eine neue Datei. Das geht gut mit dem Editor (oder einem anderen Texteditor, wie z.B. gedit). #Diese Datei werden wir später in unser Projekt einbinden, deswegen tun wir sie in den gleichen Ordner.

#Wir schreiben in diese Datei den folgenden Inhalt:

##+BEGINSRC c++ ##define WlanName "NameeuresWlans" ##define WlanPasswort "euerPasswort" ##+ENDSRC #und speichern die Datei unter "secret.h" ##+REVEAL: split

#Die Datei können wir jetzt im Hauptprogram einbinden. #Dazu schreiben wir oben unter

##+BEGINSRC c++ ##include <AdafruitNeoPixel.h> ##+ENDSRC

#noch

##+BEGINSRC c++ ##include "secrets.h" ##+ENDSRC

##+REVEAL: split

#mit ##+BEGINSRC c++ #Serial.println(WlanName); ##+ENDSRC #können wir uns jetzt ausgeben lassen, wie unser W-Lan heißt. Wenn das Klappt kennt der Arduino jetzt also den Namen unseres W-Lans.

##+REVEAL: split

#Verbindung zum WLAN

#Bibliothek einfügen Sketch -> Bibliothek einfügen -> ESP8266WiFi

##+REVEAL: split ##+BEGINSRC c++ #WiFi.begin(WlanName,WlanPasswort); #Serial.print("Verbinden mit Wlan "); #while (WiFi.status() != WLCONNECTED) #{ #Serial.print("."); #delay(500); #} ##+ENDSRC

#Serial.print("\nVerbunden, IP Addresse: "); #Serial.println(WiFi.localIP());

#Der nächste Schritt ist die Verbindung zum W-Lan. #Dazu nutzen wir die folgende Funktion:

#verbinden… (mit Serial)

#Zeit empfangen

#Umrechnen

#Ausgeben

### Danke

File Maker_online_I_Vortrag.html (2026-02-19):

# Maker online Kurs I

## Jannis Dohm

Created: 2021-12-05 So 23:03

## Herzlich Willkommen!

## Ziel / Inhalt des Kurses

- Erstellung der Hardware (4.11)
- Zusammenbau und Programmierung (25.11)
- Hilfe, Customization, Fragen / Reserve (16.12)

## Heutiges Ziel

- Jeder hat FreeCAD installiert
- Jeder hat einfaches Tonnenmodell konstruiert
- Ich werde die Tonnen für euch drucken

Wer will kann seine Tonne natürlich selbst auf einem 3D-Drucker drucken!

## Bevor wir starten:

Für den weiteren ablauf, brauche ich folgende Daten:

- Anzahl TeilnehmerInnen
- Wohnorte (für Versand der Hardware und vorbereitung der Software)

## FreeCAD Einrichten

## Erstellen der Tonne

Live demo zum Mitmachen

## Erstellung des Basic Deckels

## Möglichkeit der Personalisierung

Ihr habt jetzt noch etwas Zeit selbst an euren Projekten zu arbeiten! Bei fragen gerne an uns wenden. Spätester Abgabezeitpunkt ist Sonntag! Bitte denkt daran, ohne Datei könnt ihr nicht weiter mit machen, bei Problemen gerne bei uns melden (auch nach dem Kurs).

## Kontaktdaten

Jannis Dohm - bergisches_land@zukunftspiloten.vdi.de

Thomas Kranz - thomas.kranz@vdi-mittelhessen.de

weitere Infos - https://github.com/jdohm/ZP_Muelleimer

## Danke euch

und hoffentlich bis zum nächsten Mal :)

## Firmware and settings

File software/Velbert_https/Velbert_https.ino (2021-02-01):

#include <ESP8266WiFi.h>
#include "VelbertMuellParser.h"
#include <NTPClient.h>
#include <WiFiUdp.h>
#include <Time.h>

#include "secrets.h"

#include <Adafruit_NeoPixel.h>
#ifdef __AVR__
  #include <avr/power.h>
#endif
#define PIN       4
#define NUMPIXELS 6

Adafruit_NeoPixel pixels(NUMPIXELS, PIN, NEO_GRB + NEO_KHZ800);

WiFiUDP ntpUDP;
// By default 'pool.ntp.org' is used with 60 seconds update interval and
// no offset
//NTPClient timeClient(ntpUDP);

// You can specify the time server pool and the offset, (in seconds)
// additionaly you can specify the update interval (in milliseconds).
NTPClient timeClient(ntpUDP, "pool.ntp.org", 3600, 60000);

#define DayInSeconds 86400

VelbertMuellParser  RMP("https://service.tbv-velbert.de/abfall/abfallabfuhr-suche/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");


void setup() {
#if defined(__AVR_ATtiny85__) && (F_CPU == 16000000)
  clock_prescale_set(clock_div_1);
#endif
pixels.begin();
pinMode(LED_BUILTIN, OUTPUT);
digitalWrite(LED_BUILTIN, HIGH);

  
  Serial.begin(115200);
  Serial.println();
  Serial.println();
  Serial.println();
  timeClient.begin();
  
 
  WiFi.begin(ssid,pass);
  Serial.print("checking wifi ");
  while (WiFi.status() != WL_CONNECTED)
  {
    Serial.print(".");
    delay(500);
  }
    
  Serial.print("\nConnected, IP address: ");
  Serial.println(WiFi.localIP());

  RMP.SetStreet(street);
}

void loop()
{
  int blue;
  pixels.clear();
  timeClient.update();
  setTime(timeClient.getEpochTime()+1*DayInSeconds);
  Serial.print("date: ");
  Serial.print(day());
  Serial.print(".");
  Serial.print(month());
  Serial.print(".");
  Serial.println(year());
  Serial.print("Time: ");
  Serial.println(timeClient.getFormattedTime());
  if(year()>1971){
    if(RMP.CheckDate("Restmüll", day(),month(),year())){
      Serial.println("Heute Graue Tonne!");
      pixels.setPixelColor(2, pixels.Color(15, 15, 15));
      pixels.setPixelColor(3, pixels.Color(15, 15, 15));
    }
    if(RMP.CheckDate("Gelbe", day(),month(),year())){
      Serial.println("Heute Gelb Tonne!");
      pixels.setPixelColor(1, pixels.Color(50, 25, 0));
      pixels.setPixelColor(4, pixels.Color(50, 25, 0));
    }
    if(RMP.CheckDate("Papier-Tonne", day(),month(),year())){
      Serial.println("Heute Blau Tonne!");
      pixels.setPixelColor(0, pixels.Color(0, 0, 50));
      pixels.setPixelColor(5, pixels.Color(0, 0, 50));
      blue = 50;
    }
    else blue = 0;
    for(int ia=0; ia<30;ia++){
      for(int a=0; a<50;a++){
        for(int i=0; i <15;i++){
          pixels.setPixelColor(5, pixels.Color(0, i, blue));
          delay(70);
          pixels.show();
        }
        for(int i=0; i <15;i++){
          pixels.setPixelColor(5, pixels.Color(0, 14-i, blue));
          delay(70);
          pixels.show();
        }
      }
    }
    //      delay(300000);
  }
  else{
        for(int a=0; a<50;a++){
      for(int i=0; i <15;i++){
        pixels.setPixelColor(5, pixels.Color(i, 0, blue));
        delay(70);
        pixels.show();
      }
      for(int i=0; i <15;i++){
        pixels.setPixelColor(5, pixels.Color(14-i, 0, blue));
        delay(70);
        pixels.show();
      }
    }
  }
}

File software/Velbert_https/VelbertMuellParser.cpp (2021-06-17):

/*
    VelbertMuellParser.cpp - Library to parse the Trash website of the German city Velbert.
    This will be used to evaluate if tomorrow the trash will be emptied. 
    So that we can signal to put out the trash.
    Created by Jannis Dohm, 2020-04-20.
    Released under MIT License.
*/

#include "Arduino.h"
#include "VelbertMuellParser.h"
#include <ESP8266HTTPClient.h>
#include <WiFiClientSecureBearSSL.h>

//_DatabaseURL = "https://service.tbv-velbert.de/abfall/abfallabfuhr-suche/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";

VelbertMuellParser::VelbertMuellParser(char *DatabaseURL){//the URL needs to be checked on the official website "https://abfallkalenderVelbert.insert-infotech.de/index.php"
    _DatabaseURL =  DatabaseURL;
}

void VelbertMuellParser::SetStreet(String Street){//Enter your Streetname
  _Street = Street;
//  return 0;
}

bool VelbertMuellParser::CheckDate(char* SearchFor, int day, int month, int year){
    std::unique_ptr<BearSSL::WiFiClientSecure>client(new BearSSL::WiFiClientSecure);
    client->setInsecure();
    HTTPClient https;

    String postData = "tx_tbvabfall_strassensuche%5B__referrer%5D%5B%40extension%5D=Tbvabfall&tx_tbvabfall_strassensuche%5B__referrer%5D%5B%40vendor%5D=EveryConsult&tx_tbvabfall_strassensuche%5B__referrer%5D%5B%40controller%5D=Abfalldaten&tx_tbvabfall_strassensuche%5B__referrer%5D%5B%40action%5D=list&tx_tbvabfall_strassensuche%5B__referrer%5D%5Barguments%5D=YTo0OntzOjY6ImFjdGlvbiI7czo0OiJsaXN0IjtzOjEwOiJjb250cm9sbGVyIjtzOjExOiJBYmZhbGxkYXRlbiI7czoxMToiYWJnZXNjaGlja3QiO3M6MToiMSI7czoxMToic3VjaGJlZ3JpZmYiO3M6MTI6IkhhdXB0c3RyYcOfZSI7fQ%3D%3Dd6c50c9284915c804ecfe2866784057e0ee2985c&tx_tbvabfall_strassensuche%5B__referrer%5D%5B%40request%5D=a%3A4%3A%7Bs%3A10%3A%22%40extension%22%3Bs%3A9%3A%22Tbvabfall%22%3Bs%3A11%3A%22%40controller%22%3Bs%3A11%3A%22Abfalldaten%22%3Bs%3A7%3A%22%40action%22%3Bs%3A4%3A%22list%22%3Bs%3A7%3A%22%40vendor%22%3Bs%3A12%3A%22EveryConsult%22%3B%7D1b4dce7c057e7503073a6937f97eee8e8b7650e3&tx_tbvabfall_strassensuche%5B__trustedProperties%5D=a%3A2%3A%7Bs%3A11%3A%22abgeschickt%22%3Bi%3A1%3Bs%3A11%3A%22suchbegriff%22%3Bi%3A1%3B%7Dae8a10e23f532f6ce1dd43681b3c3b0c393dedc7&tx_tbvabfall_strassensuche%5Babgeschickt%5D=1&tx_tbvabfall_strassensuche%5Bsuchbegriff%5D=" + _Street;

//    Serial.println("postData: ");
//    Serial.println(postData);
  if (https.begin(*client, String(_DatabaseURL))) {  // HTTPS
    Serial.println("[HTTPS] POST...");
    //https.addHeader("Content-Type", "text/plain");
    https.addHeader("Content-Type", "application/x-www-form-urlencoded");
    int httpCode = https.POST(postData);

    // httpCode will be negative on error
    if (httpCode > 0) {
      // HTTP header has been send and Server response header has been handled
    Serial.printf("[HTTPS] POST... code: %d\n", httpCode);
      // file found at server?
    if (httpCode == HTTP_CODE_OK) {
        int payload = https.getSize();
        Serial.println(String("[HTTPS] Received payload: ") + payload);
        Stream *httpsS = https.getStreamPtr();
        while(httpsS -> available()){

//        String line = httpsS -> readStringUntil('\n');
//        Serial.println(line);

        String line;
        if(httpsS -> find(SearchFor)){
            Serial.print("found ");
            Serial.println(SearchFor);
        }
        for(int i=0; i<3;i++){
          line = httpsS -> readStringUntil('\n');
          Serial.print(" looking for ");
          String _SDate = _ToTwoString(day) + "." + _ToTwoString(month) + "." + year;
          Serial.print(_SDate);
          Serial.println(" in the following line:");
          Serial.println(line);
          if(1 <= line.indexOf(_SDate)) {
            Serial.println("found it!");
            return true;
          }
        }
        Serial.println("not found!");
        return false;
        }
    }
    } else {
    Serial.printf("[HTTPS] POST... failed, error: %s\n\r", https.errorToString(httpCode).c_str());
    }

    https.end();
  } else {
    Serial.printf("[HTTPS] Unable to connect\n\r");
  }
  return false;
}

String VelbertMuellParser::_ToTwoString(int Num){
    if(Num<0) return "00";
    if(Num<10) return "0" + String(Num);
    return String(Num);
}

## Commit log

2020-03-26 Added simple 3D-Parts
    Version 0.0.3
    [Trashcan_bottom.FCStd, Trashcan_bottom.stl, top_simple.FCStd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]
2020-03-26 added work in Progress advanced 3D-Parts
    Version 0.0.4
    [Trashcan_bottom.FCStd, Trashcan_bottom.stl, top_advanced.FCStd]
2020-03-26 Added LED-Strip Test programm
    Example program by Adafruit:
    https://github.com/adafruit/Adafruit_NeoPixel
    Only changed to fit our Pins and count of LED
    Version 0.0.5
2020-03-30 fixed error where notifications where missing on the first day of a month
    date+1 is now calculated on linux time level
    instead of adding one day
    (which resultet in March the 32 instead of April the 1)
    Version 0.0.8
    [Muellmax_Bochum_ICS.ino]
2021-06-17 Das Bochum Beispiel wurde auf die Minimalausführung gekürzt
    Um Teilnehmer nicht mit zusätzlichen und komplizierten Funktionen zu
    überwältigen habe ich ein minimal Beispiel erstellt.
2021-12-05 Update to Vortrag
    Die verschiedenen Vorträge als html Files hinzugefügt und Arbeiten in vortrag.org
